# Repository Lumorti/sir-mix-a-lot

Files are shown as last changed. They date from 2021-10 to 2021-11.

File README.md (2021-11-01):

### Background

A few years ago I made a [machine to mix cocktails](https://github.com/Lumorti/drink-182), but after testing it at a party it didn't work as well as I expected, due to various issues with leakage and the touch screen not working well. So here I present the revised version: Sir Mix-a-Lot (no relation). This time it uses just an Arduino for simplicity, only uses four liquids for cost reasons, uses dials to choose the ratios rather than a touchscreen, and the pumps are peristalic meaning they don't need to be gravity fed. All of this housed inside a simple cardboard box (to avoid having to saw wood like last time).

### Photo taken just before the debut Halloween party

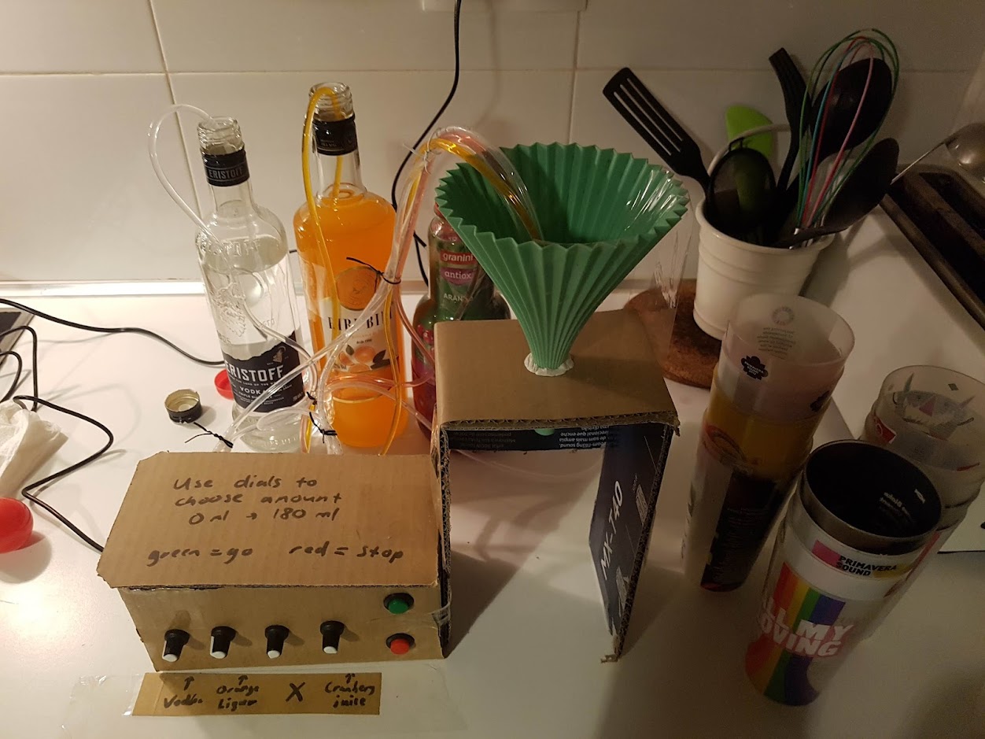
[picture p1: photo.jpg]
Photo of the machine


### Usage

- use the dials to choose the amounts of each of the four liquids (between 0 and 180 ml)
- use the go button to pour it 
- use the stop button if you want only a partial pour

### Diagram

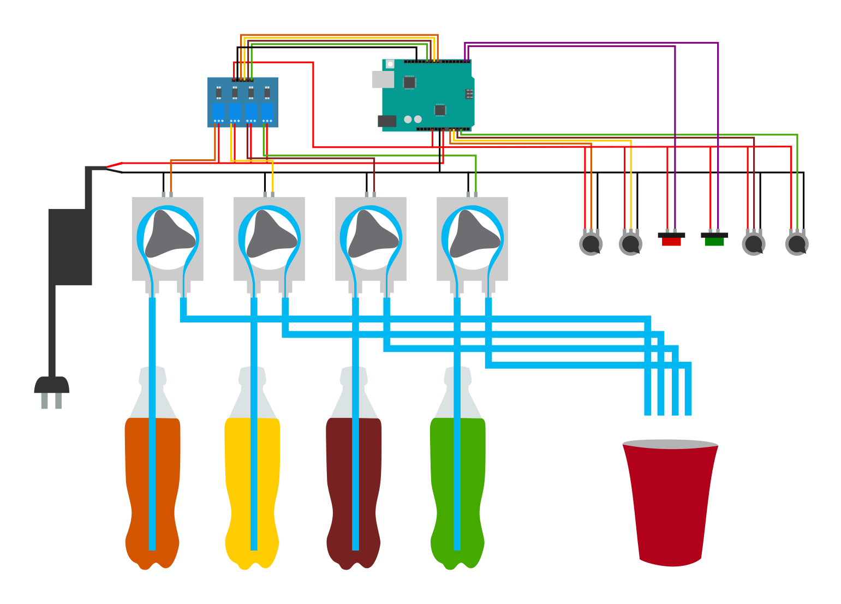
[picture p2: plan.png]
Circuit diagram for this project


### Parts Required

- standard Arduino
- power supply (12 V, 3 A)
- optocoupler with at least 4 channels
- 2 buttons
- 4 potentiometers
- 4 peristaltic pumps (12 V)
- silicon tubing of the same dimension of the pump (I used 3 mm * 5 mm)
- resistors and jumper cables for general wiring

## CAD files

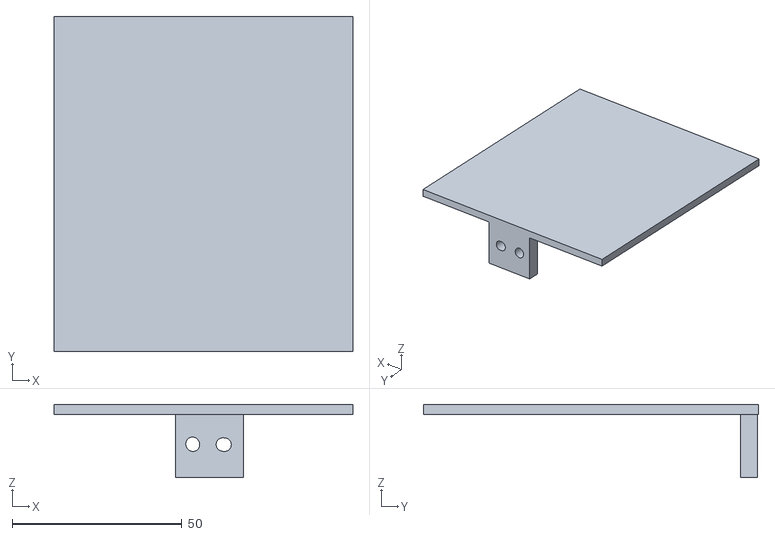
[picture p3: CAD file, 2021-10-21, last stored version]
model/topLeft.stl
87.9 x 98.6 x 21.6

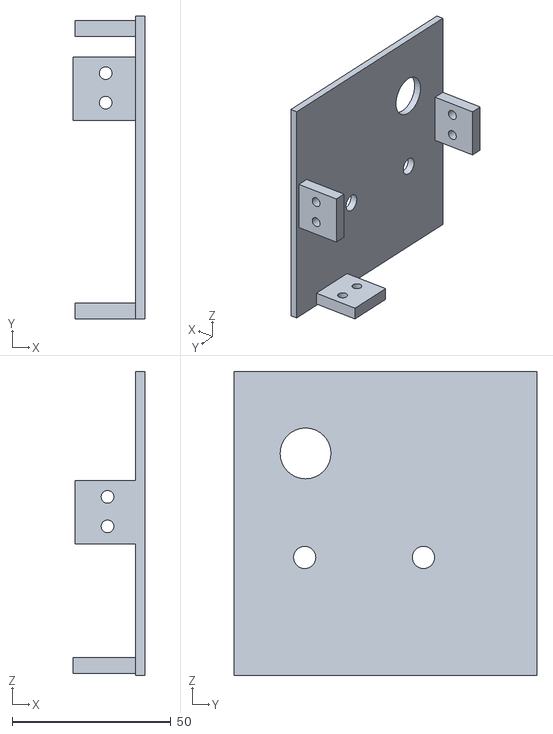
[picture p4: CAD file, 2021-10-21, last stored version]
model/frontRight.stl
22.7 x 95.4 x 95.7

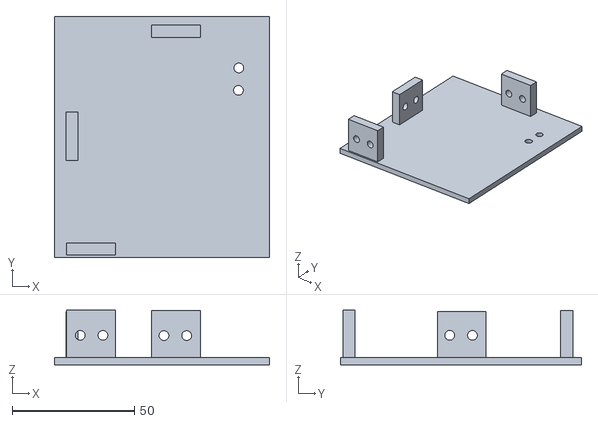
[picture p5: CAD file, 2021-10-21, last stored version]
model/bottomRight.stl
87.9 x 98.6 x 22.3

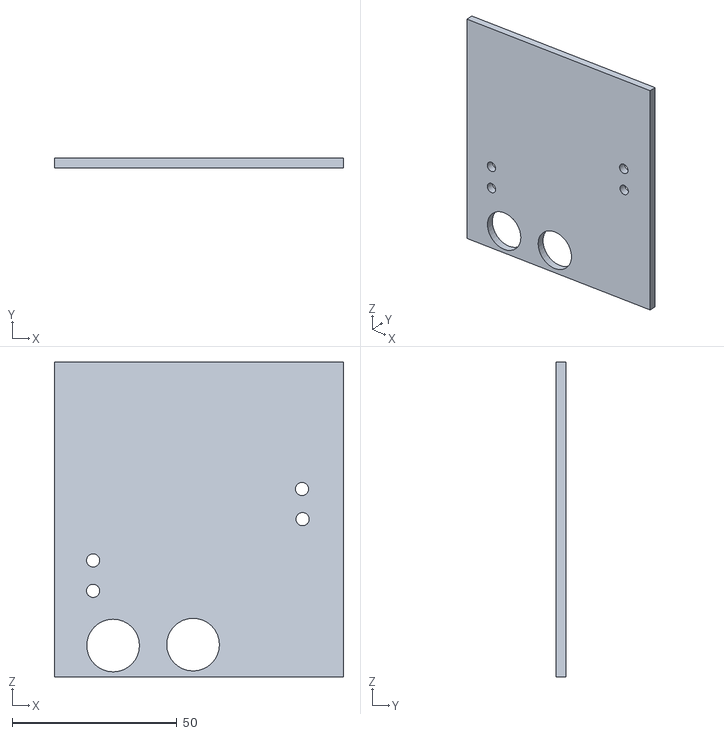
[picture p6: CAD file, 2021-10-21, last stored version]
model/sideLeft.stl
87.9 x 3.00 x 95.7

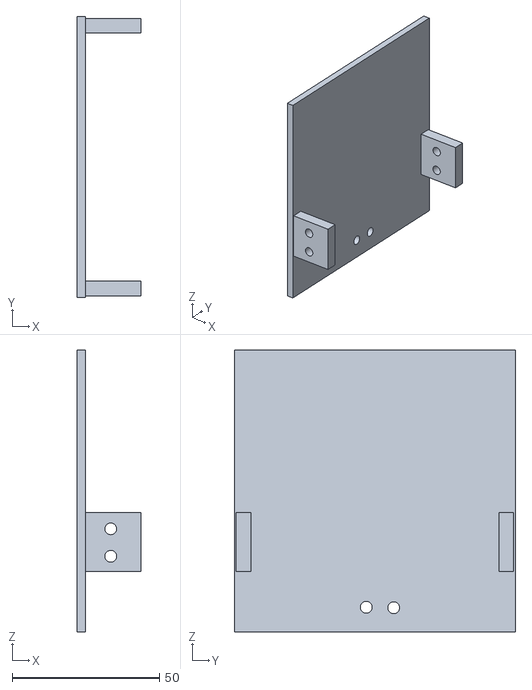
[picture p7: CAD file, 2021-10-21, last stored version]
model/backRight.stl
21.8 x 95.4 x 95.7

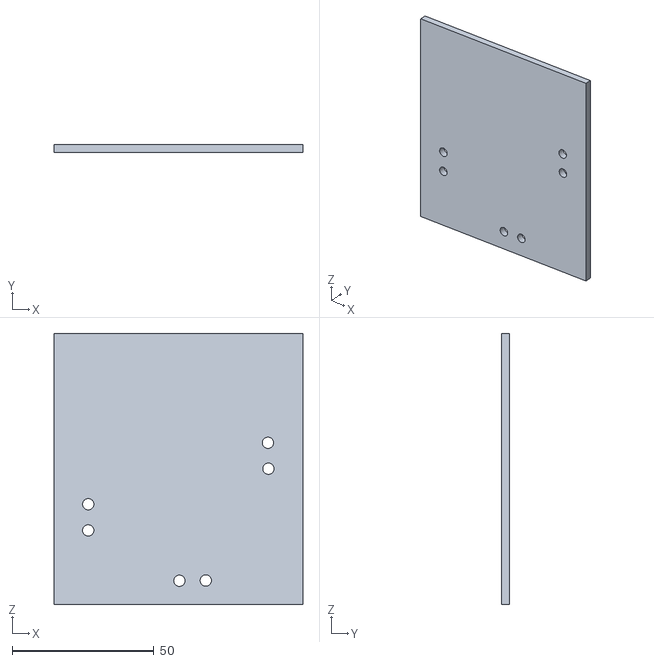
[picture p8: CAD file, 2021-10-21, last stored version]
model/sideRight.stl
87.9 x 3.00 x 95.7

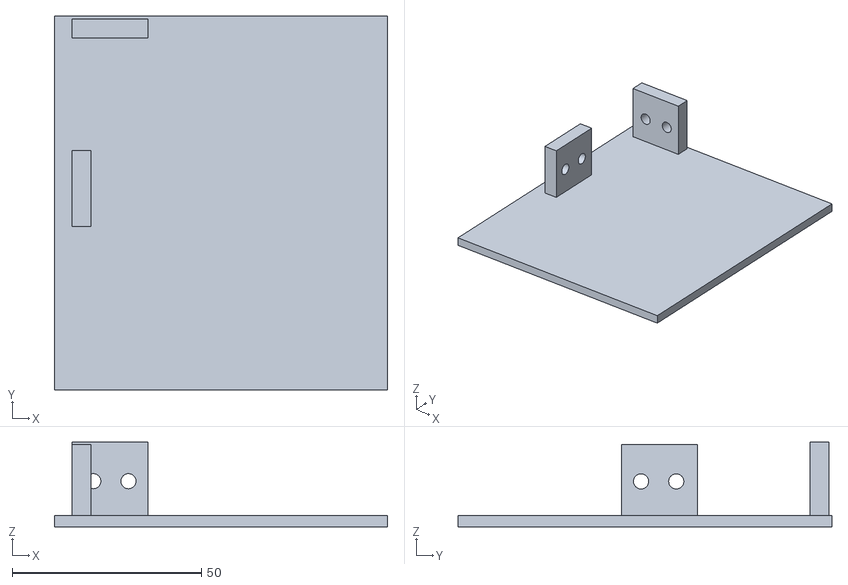
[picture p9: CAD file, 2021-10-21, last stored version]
model/bottomLeft.stl
87.9 x 98.6 x 22.3

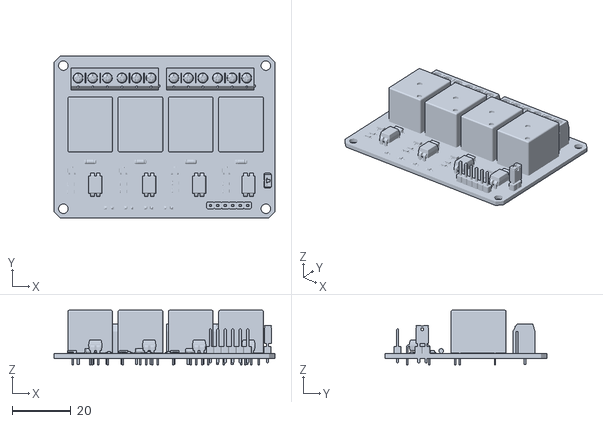
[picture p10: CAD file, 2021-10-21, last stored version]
model/4 Channel Relay Board.stl
75.3 x 55.2 x 18.6

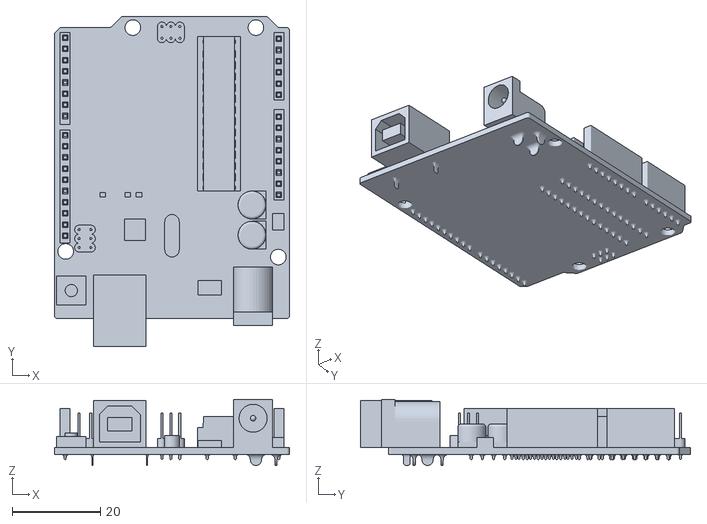
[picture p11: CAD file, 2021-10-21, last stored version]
model/Arduino.stl
53.3 x 74.9 x 15.0

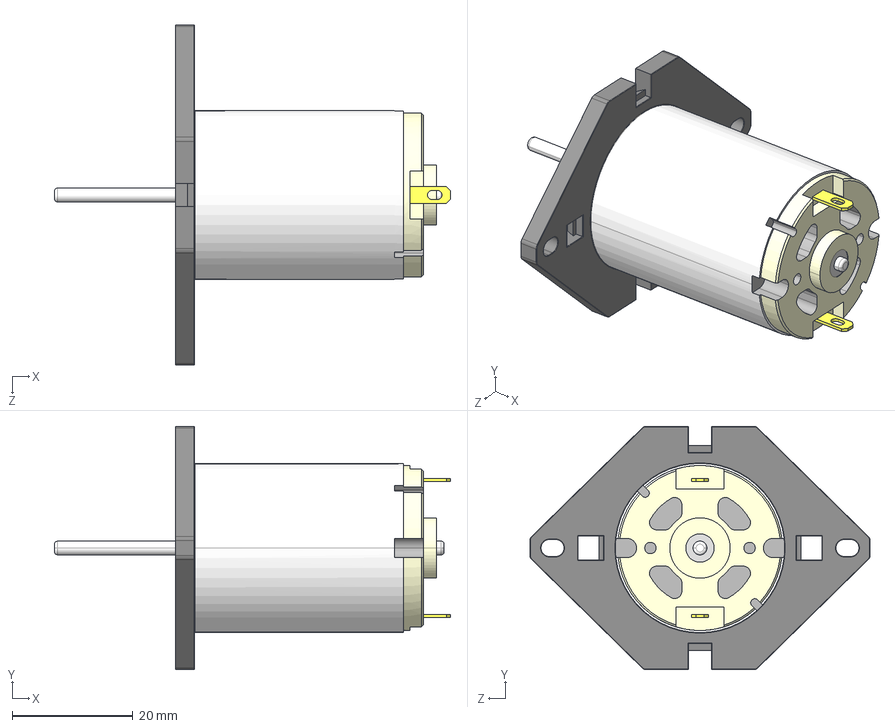
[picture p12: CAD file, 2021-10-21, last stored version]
model/Adafruit peristaltic pump.IGS
65.5 x 40.2 x 56.3 mm

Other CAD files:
model/topRight.stl
model/backLeft.stl
model/frontLeft.stl
model/Adafruit peristaltic pump.stl

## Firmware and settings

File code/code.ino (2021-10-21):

// Pin numbers
const int buttonPower = 4;
const int buttonStart = 2;
const int buttonStop = 3;
const int dial1 = A2; // blue
const int dial2 = A3; // green
const int dial3 = A4; // yellow
const int dial4 = A5; // orange
const int opto1 = 8; // blue
const int opto2 = 9; // green
const int opto3 = 10; // yellow
const int opto4 = 11; // orange

// Maxs for the analog values
const long max1 = 681;
const long max2 = 681;
const long max3 = 681;
const long max4 = 681;

// How long to pour for max for each valve
// For 3x5 it's approx 80ml / min
const long maxPour1 = 120000;
const long maxPour2 = 120000;
const long maxPour3 = 120000;
const long maxPour4 = 120000;

// For reading data
long state1 = 0;
long state2 = 0;
long state3 = 0;
long state4 = 0;

// Whether the system is doing nothing (0), pouring (1)
boolean isPouring = false;

// How long to wait between iterations
int milliPer = 5;

// Runs once at the start
void setup(){
  
  // Init the input pins
  pinMode(buttonStart, INPUT_PULLUP);
  pinMode(buttonStop, INPUT_PULLUP);
  pinMode(dial1, INPUT);
  pinMode(dial2, INPUT);
  pinMode(dial3, INPUT);
  pinMode(dial4, INPUT);
  
  // Init the output pins
  pinMode(opto1, OUTPUT);
  pinMode(opto2, OUTPUT);
  pinMode(opto3, OUTPUT);
  pinMode(opto4, OUTPUT);
  pinMode(buttonPower, OUTPUT);
  digitalWrite(opto1, HIGH); 
  digitalWrite(opto2, HIGH); 
  digitalWrite(opto3, HIGH); 
  digitalWrite(opto4, HIGH);
  digitalWrite(buttonPower, HIGH);
  
}

// Convert the analog value to milliseconds
long analogToMilli(int analog, long maxVal, long maxPour) {
  return (maxPour * analog) / maxVal;
}

// Runs forever after the setup
void loop() {
  
  // If not doing anything yet
  if (!isPouring) {

    // If the start button is pressed
    if (digitalRead(buttonStart) == LOW) {
      
      // Start pouring
      isPouring = true;
      
      // Get the amounts from the dials and convert
      state1 = analogToMilli(analogRead(dial1), max1, maxPour1);
      state2 = analogToMilli(analogRead(dial2), max2, maxPour2);
      state3 = analogToMilli(analogRead(dial3), max3, maxPour3);
      state4 = analogToMilli(analogRead(dial4), max4, maxPour4);
      
      // Start pouring
      if (state1 > 0) {
        digitalWrite(opto1, LOW);
      } 
      if (state2 > 0) {
        digitalWrite(opto2, LOW);
      }
      if (state3 > 0) {
        digitalWrite(opto3, LOW); 
      }
      if (state4 > 0) {
        digitalWrite(opto4, LOW);
      }
      
    }
    
  // If currently pouring
  } else {
    
    // If the stop button is pressed
    if (digitalRead(buttonStop) == LOW) {
      
      // Stop pouring
      isPouring = false;
      state1 = 0;
      state2 = 0;
      state3 = 0;
      state4 = 0;
      digitalWrite(opto1, HIGH); 
      digitalWrite(opto2, HIGH); 
      digitalWrite(opto3, HIGH); 
      digitalWrite(opto4, HIGH); 
      
    // Otherwise pour
    } else {
      
      // Check if liquid 1 should keep pouring
      if (state1 > 0) {
        state1 -= milliPer;
        if (state1 <= 0) {
          digitalWrite(opto1, HIGH); 
        }
      }
      
      // Check if liquid 2 should keep pouring
      if (state2 > 0) {
        state2 -= milliPer;
        if (state2 <= 0) {
          digitalWrite(opto2, HIGH); 
        }
      }
      
      // Check if liquid 3 should keep pouring
      if (state3 > 0) {
        state3 -= milliPer;
        if (state3 <= 0) {
          digitalWrite(opto3, HIGH); 
        }
      }
      
      // Check if liquid 5 should keep pouring
      if (state4 > 0) {
        state4 -= milliPer;
        if (state4 <= 0) {
          digitalWrite(opto4, HIGH); 
        }
      }
      
      // Once all are finished, stop
      if (state1 <= 0 && state2 <= 0 && state3 <=0 && state4 <= 0) {
        
        // Reset the state
        isPouring = false;
        state1 = 0;
        state2 = 0;
        state3 = 0;
        state4 = 0;
      
      }
    
    }
    
  }
  
  // Slight delay for timings
  delay(milliPer);
  
}

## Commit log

2021-07-16 added start of Arduino code
2021-10-21 first draft of model
    [4 Channel Relay Board.stl, Adafruit peristaltic pump.IGS, Adafruit peristaltic pump.stl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]
2021-10-21 removed unused files
    [Adafruit peristaltic pump.IGS]
2021-10-21 finish first draft of model
    [backLeft.stl, backRight.stl, bottomLeft.stl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]
2021-11-01 added photo
    [4 Channel Relay Board.stl, Adafruit peristaltic pump.stl, Arduino.stl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]
